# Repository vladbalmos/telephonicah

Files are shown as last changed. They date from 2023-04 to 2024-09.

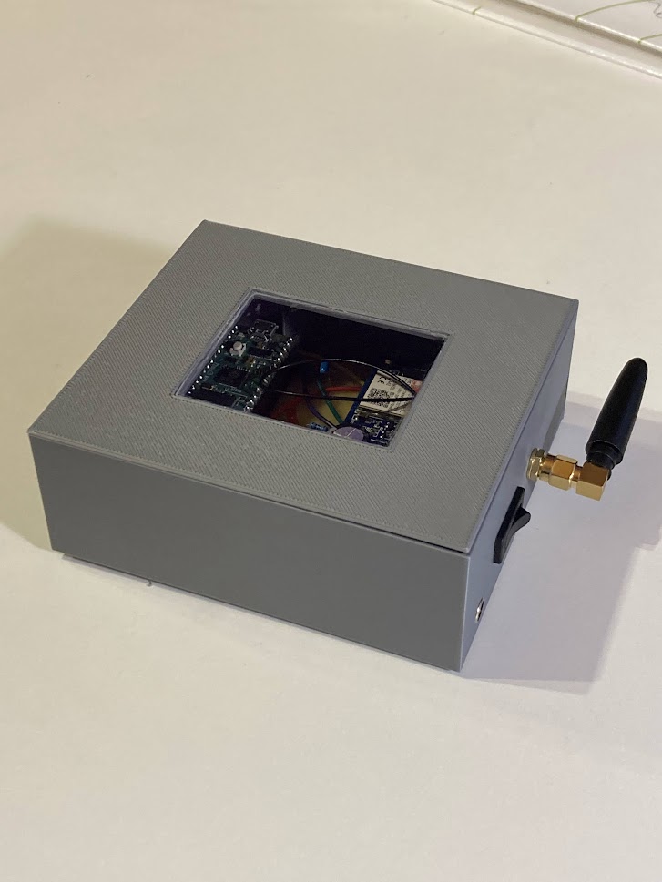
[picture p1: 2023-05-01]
hw/telephonicah.jpg

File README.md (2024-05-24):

# UPDATE
The original version of this project is on branch `original-call-proxy`. The `master` branch doesn't forward calls to a designated number, instead it activates an external connected remote control using the signal port (see the schematic in the `hw` folder for the signal port pinout).
# Telephonicah

This repo contains firmware and hardware related resources (schematic, pcb & enclosure 3d models) for a device used to proxy GSM calls to a designated number (ex: parking barrier gate).

Hardware requirements:

    * Raspberry Pi Pico W
    * SIM800 GSM Module
    * 5V@2.5A power supply
    * capacitors: 100nf, 4.7uf, 2200uf
    * resistors: 2x150ohm, 1Mohm
    * leds: red, green
    
The Pico controls the SIM800 module via UART.

Features:

    * SMS based commands:
        * get remaining credit
        * delete SIM stored SMSs
        * connect to wifi
        * query wifi status
    * Relay received SMS to designated owner number
    * Web UI
    
After the devices connects to WIFI it will bind the webserver to port 8080 and a SMS containing the server's ip address and port will be sent to the administrator's phone number

# System requirements
* micropython
* ampy (pip3 install adafruit-ampy)
* minicom (optional)

# Development

## Linux
Build micropython:

    cd [mycropython-dir]
    make -C mpy-cross

    cd [mycropython-dir]/ports/rp2
    make -j4 BOARD=PICO_W submodules
    make -j4 BOARD=PICO_W clean
    make -j4 BOARD=PICO_W
    
After building copy the micropython firmware to a pico

Init:
    ./setup.sh
    # edit src/phone_numbers.py and add phone numbers
    make build
    
Run:

    make run
    
Clean

    make clean
    
Build

    make build

## Windows
Build micropython https://github.com/micropython/micropython/tree/master/ports/windows

After building copy the micropython firmware to a pico

Edit `build.ps1` and change the $PORT variable to the correct serial port (ex: com1)
Init:

    .\setup.ps1
    # edit src/phone_numbers.py and add phone numbers
    .\build.ps1 -Command build
    
Run:

    .\build.ps1 -Command run

Clean:

    .\build.ps1 -Command clean
    
Build:

    .\build.ps1 -Command build

List files on pico:

    .\build.ps1 -Command list
    
Copy file from pico:

    .\build.ps1 -Command get -Argument [filename]
    
Copy file to pico:

    .\build.ps1 -Command send -Argument [filename]

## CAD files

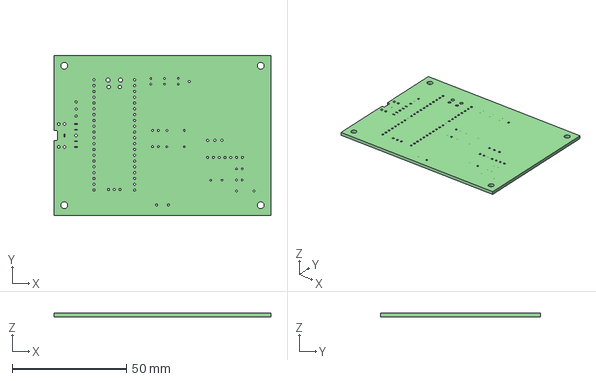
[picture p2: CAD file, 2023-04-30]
hw/board/telephonica/telephonica.step
95.0 x 70.0 x 1.60 mm

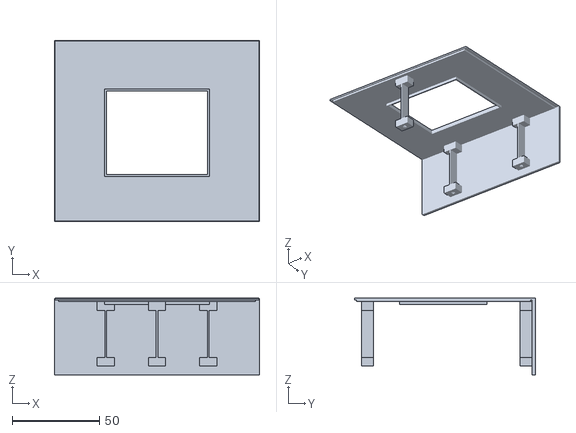
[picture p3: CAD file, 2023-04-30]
hw/case/body-Part_Lid.stl
117.5 x 104.0 x 44.0

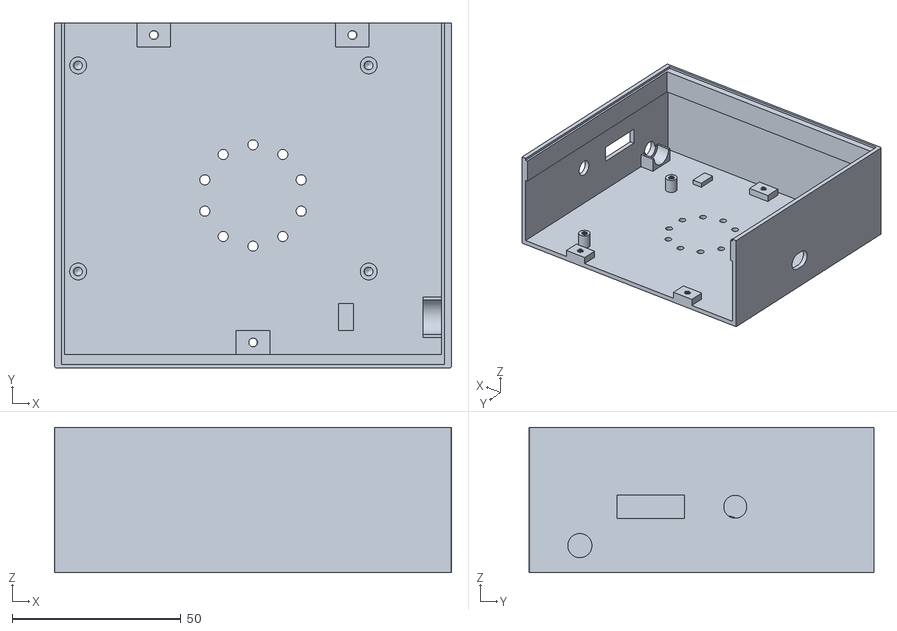
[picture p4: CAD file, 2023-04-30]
hw/case/body-Part_Body.stl
117.5 x 102.0 x 43.0

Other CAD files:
hw/case/pcb.stl

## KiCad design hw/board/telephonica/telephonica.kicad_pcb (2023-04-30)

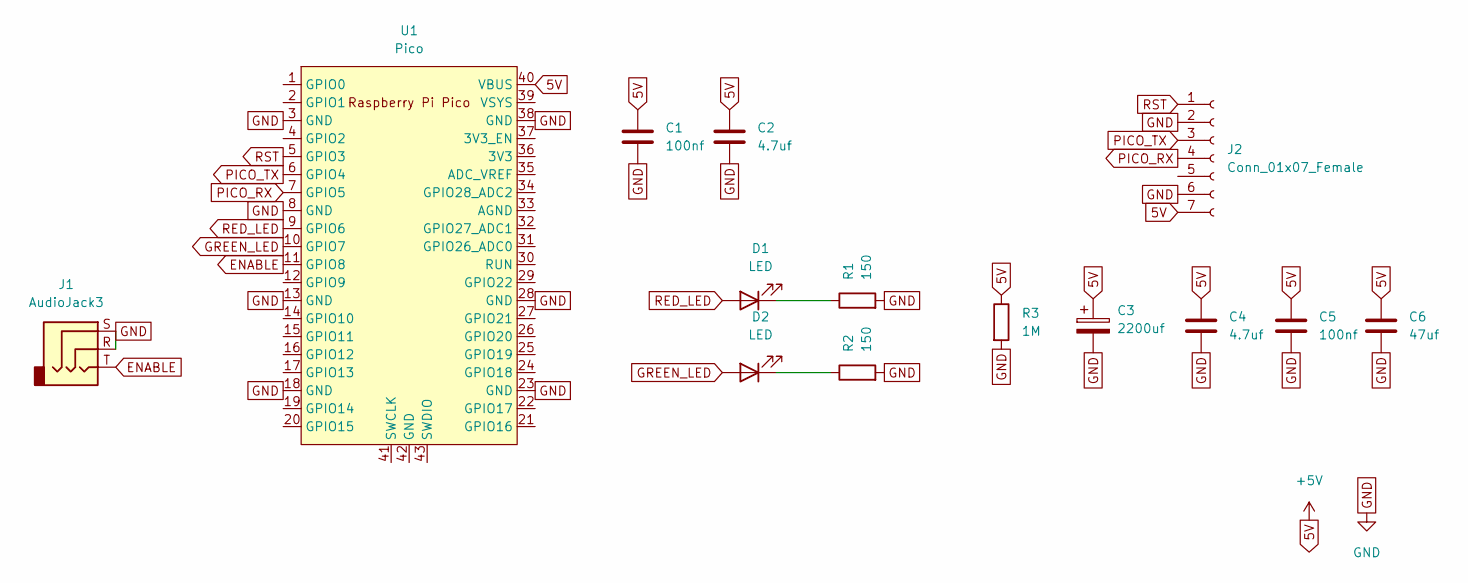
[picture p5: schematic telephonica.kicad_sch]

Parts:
C1, C5: 100nf; C_Disc_D3.8mm_W2.6mm_P2.50mm
C2, C4: 4.7uf; C_Disc_D3.8mm_W2.6mm_P2.50mm
C3: 2200uf; C_Radial_D12.5mm_H20.0mm_P5.00mm
C6: 47uf; C_Disc_D3.8mm_W2.6mm_P2.50mm
D1, D2: LED; LED_D5.0mm
J1: AudioJack3; Jack_3.5mm_CUI_SJ1-3525N_Horizontal
J2: Conn_01x07_Female; PinHeader_1x07_P2.54mm_Vertical
R1, R2: 150; R_Axial_DIN0207_L6.3mm_D2.5mm_P7.62mm_Horizontal
R3: 1M; R_Axial_DIN0207_L6.3mm_D2.5mm_P7.62mm_Horizontal
U1: Pico; RPi_Pico_SMD_TH

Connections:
5V: C1.1, C2.1, C3.1, C4.1, C5.1, C6.1, J2.7, R3.1, U1.40 (VBUS)
ENABLE: J1.T, U1.11 (GPIO8)
GND: C1.2, C2.2, C3.2, C4.2, C5.2, C6.2, J1.R, J1.S, J2.2, J2.6, R1.2, R2.2, R3.2, U1.3 (GND), U1.8 (GND), U1.13 (GND), U1.18 (GND), U1.23 (GND), U1.28 (GND), U1.38 (GND)
GREEN_LED: D2.2 (A), U1.10 (GPIO7)
unnamed: D1.1 (K), R1.1
unnamed: D2.1 (K), R2.1
PICO_RX: J2.4, U1.7 (GPIO5)
PICO_TX: J2.3, U1.6 (GPIO4)
RED_LED: D1.2 (A), U1.9 (GPIO6)
RST: J2.1, U1.5 (GPIO3)

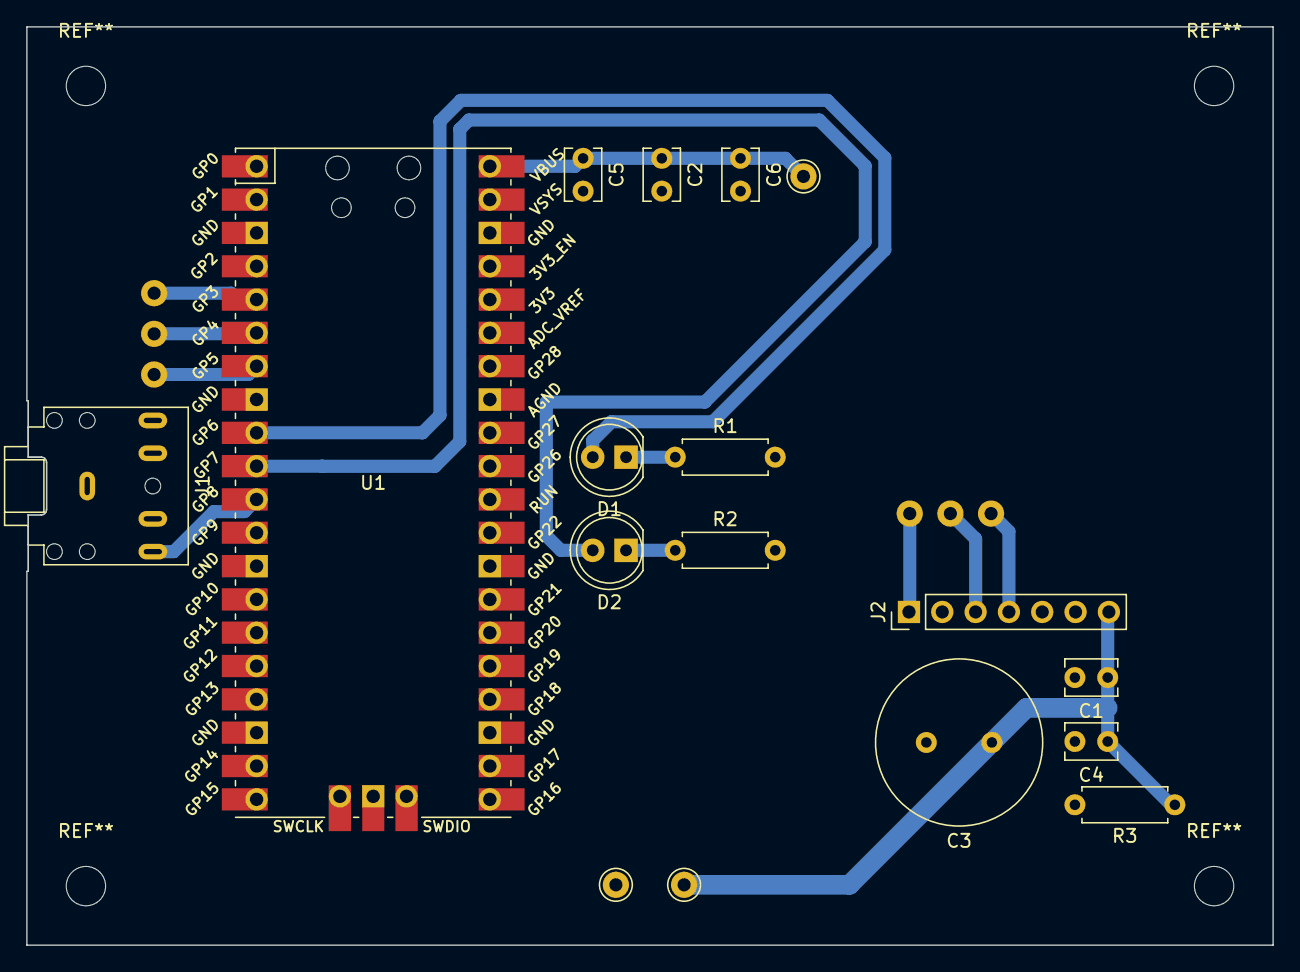
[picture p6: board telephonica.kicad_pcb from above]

Board: 2 copper layers, 95.0 x 70.0 mm, 14 parts (0 on the bottom side), 10 nets.

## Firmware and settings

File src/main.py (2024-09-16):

import machine
import uasyncio as asyncio
import json
import time
import sim800l
import os
import uart
from dynamic_queue import Queue
import phone_numbers
import led_notif
import webserver

SLEEP_MS = 50

RST_PIN = 3
TX_PIN = 4
RX_PIN = 5
RED_LED_PIN = 6
GREEN_LED_PIN = 7
ENABLE_PIN = 8

watchdog = machine.WDT(timeout=8000)
watchdog.feed()
wifi_status_sms_sent = False
last_reset = None
sim_reset_counts = 0

reset_pin = machine.Pin(RST_PIN, machine.Pin.OUT)
reset_pin.high()

enable_pin = machine.Pin(ENABLE_PIN, machine.Pin.OUT)
enable_pin.low()

state = {
    'gate_number': phone_numbers.GATE_NUMBER,
    'owner_number': phone_numbers.OWNER_NUMBER,
    'ep_toggle_duration': 500,
    'allowed_callers': phone_numbers.ALLOWED_CALLERS.copy(),
    'ssid': None,
    'ssid_password': None
}

available_commands = [
    'get:credit',
    'delete:sms',
    'clear:state',
    'wifi:status',
    'wifi:connect\nssid\npassword'
]

async def sleep(ms = SLEEP_MS):
    return await asyncio.sleep_ms(ms)

async def toggle_enable_pin(duration = 500):
    print('Toggling ENABLE PIN for', duration, 'ms')
    enable_pin.high()
    await sleep(duration)
    enable_pin.low()

async def main():
    global state
    global wifi_status_sms_sent
    
    led = machine.Pin('LED', machine.Pin.OUT)
    red_led = machine.Pin(RED_LED_PIN, machine.Pin.OUT)
    green_led = machine.Pin(GREEN_LED_PIN, machine.Pin.OUT)
    
    led_notif.initialize(red_led, green_led)

    device_queue = Queue(24)
    debug_queue = Queue(24)
    command_queue = Queue(8)

    uart_config = {
        'tx': machine.Pin(TX_PIN, machine.Pin.OUT),
        'rx': machine.Pin(RX_PIN, machine.Pin.IN),
        'timeout': 250
    }

    reader, writer = await uart.initialize(uart_config)
    asyncio.create_task(sim800l.initialize(device_queue, debug_queue, reader, writer, watchdog))
    
    watchdog.feed()
    try:
        with open('state.json', 'r') as state_file:
            contents = state_file.read()
            state = json.loads(contents)
    except Exception as e:
        print('No last state found')

    if state['ssid'] and state['ssid_password']:
        asyncio.create_task(webserver.initialize(command_queue, state, state['ssid'], state['ssid_password']))
        
    credit_info = ''
    last_credit_info_msg = None
    last_event = 0
    failed_wifi_connects = 0
    wifi_connected = False
    first_time_initialized = False
    loop_start = time.ticks_ms()
        
    watchdog.feed()

    while True:
        led.toggle()
        now = time.ticks_ms()
        
        if not first_time_initialized:
            elapsed_initalization = time.ticks_diff(now, loop_start)
            
            if elapsed_initalization < (60 * 1000):
                print("Feeding watch dog while initializing")
                watchdog.feed()

        if last_credit_info_msg:
            last_event = now
            diff = time.ticks_diff(now, last_credit_info_msg)
            if diff > 10 * 1000:
                asyncio.create_task(sim800l.send_sms_with_lock(state['owner_number'], credit_info))
                credit_info = ''
                last_credit_info_msg = None
            
        while not device_queue.empty():
            last_event = now
            event = device_queue.get_nowait()
            log_event = True

            if event['event'] == 'incoming-event':
                log_event = False
                led_notif.start_blink_green(1000)
                print('device', event)
            elif event['event'] == 'outgoing-event':
                log_event = False
                led_notif.start_blink_green(3000)
                print('device', event)
            elif event['event'] == 'initializing':
                log_event = False
                led_notif.start_blink_red()
                print('device', event)
            elif event['event'] == 'initialized':
                first_time_initialized = True
                print("Feeding watch dog")
                watchdog.feed()
                log_event = False
                await led_notif.stop_blink_red()
            else:
                print('device', event)

            if log_event:
                webserver.logs_queue.put_nowait(event)
                
            if event['event'] == 'incoming-call':
                caller = event['caller']
                if caller in state['allowed_callers']:
                    asyncio.create_task(toggle_enable_pin(int(state['ep_toggle_duration'])))
                    asyncio.create_task(sim800l.open_gate(state['gate_number'], caller))
                else:
                    await sim800l.decline_call()
            
            if event['event'] == 'incoming-sms':
                if type(event['data']) is tuple and len(event['data']) == 3:
                    msg_details = event['data'][2] or []
                    msg_from_owner = False
                    msg_from_credit_info = False
                    await sim800l.delete_sms(event['index'])
                    for d in msg_details:
                        if state['owner_number'] in d:
                            msg_from_owner = True
                            break
                        if "Credit Info" in d:
                            msg_from_credit_info = True
                            break
                        
                    if msg_from_owner:
                        msg = event['data'][2]
                        msg = '\n'.join(msg[1:])
                        original_msg = msg
                        if msg:
                            msg = msg.lower().strip()
                        if msg == 'help:':
                            msg = '\n'.join(available_commands)
                            asyncio.create_task(sim800l.send_sms_with_lock(state['owner_number'], msg))
                        if msg == 'get:credit':
                            asyncio.create_task(sim800l.check_credit())
                        elif msg == 'delete:sms':
                            await sim800l.delete_sms(aquire_lock=True, delete_all=True)
                        elif msg == 'clear:state':
                            print('Clearing state and rebooting')
                            try:
                                os.remove('state.json')
                                print('State removed. Rebooting')
                                return machine.reset()
                            except:
                                print('No state to clear')
                        elif msg == 'wifi:status':
                            wifi_status, details = webserver.status()
                            msg = f'Status: {wifi_status}\n Details: {json.dumps(details)}'
                            asyncio.create_task(sim800l.send_sms_with_lock(state['owner_number'], msg))
                        elif 'wifi:connect' in msg:
                            segments = original_msg.strip().split('\n')
                            if len(segments) != 3:
                                continue
                            
                            ssid = segments[1]
                            password = segments[2]
                            asyncio.create_task(webserver.initialize(command_queue, state, ssid, password))
                            print(f'Will connect to {ssid}/{password}')
                    elif msg_from_credit_info:
                        msg = event['data'][2]
                        msg = '\n'.join(msg[1:])
                        credit_info = f'{credit_info}{msg}'
                        last_credit_info_msg = time.ticks_ms()
                
        while not debug_queue.empty():
            last_event = now
            info = debug_queue.get_nowait()
            webserver.logs_queue.put_nowait(info)
            print('debug', info)
            
        state_modified = False
        while not command_queue.empty():
            last_event = now
            cmd = command_queue.get_nowait()
            print('command', cmd)
            webserver.logs_queue.put_nowait(cmd)
            if cmd['do'] == 'notif-wifi-connecting':
                led_notif.start_blink_red()
            
            if cmd['do'] == 'reset':
                print('Reseting...')
                machine.reset()
            if cmd['do'] == 'enter-debug':
                sim800l.toggle_debug_mode(True)
            if cmd['do'] == 'delete-all-sms':
                print('Deleting all sms')
                await sim800l.delete_sms(aquire_lock=True, delete_all=True)
            if cmd['do'] == 'send-at-command':
                await sim800l.send_at_command(cmd['payload']);
            if cmd['do'] == 'update-allowed-callers':
                new_dict = {}
                for name, number in cmd['payload']:
                    new_dict[number] = name
                state['allowed_callers'] = new_dict
                state_modified = True
            elif cmd['do'] == 'update-gate-number':
                state['gate_number'] = cmd['payload']
                state_modified = True
            elif cmd['do'] == 'update-ep-toggle-duration':
                try:
                    state['ep_toggle_duration'] = int(cmd['payload'])
                    state_modified = True
                except:
                    pass
            elif cmd['do'] == 'update-owner-number':
                state['owner_number'] = cmd['payload']
                state_modified = True
            elif cmd['do'] == 'check-credit':
                asyncio.create_task(sim800l.check_credit())
            elif cmd['do'] == 'handle-wifi-status':
                await led_notif.stop_blink_red()
                result = cmd['payload']
                if result['status']:
                    state['ssid'] = result['ssid']
                    state['ssid_password'] = result['password']
                    state['ip'] = result['ip']
                    state['port'] = result['port']
                    state_modified = True
                    
                    ip = state['ip']
                    port = state['port']
                    msg = f'Connected: {ip}:{port}'
                    wifi_connected = True
                else:
                    failed_wifi_connects += 1
                    try:
                        error_code = webserver.wifi_status_codes[result['code']]
                    except KeyError:
                        error_code = 'unknown-status'
                    msg = f'Unable to connect to wifi: {error_code}'
                    
                if not wifi_status_sms_sent:
                    if wifi_connected or failed_wifi_connects >= 5:
                        asyncio.create_task(sim800l.send_sms_with_lock(state['owner_number'], msg))
                        wifi_status_sms_sent = True
            else:
                continue
                
        if state_modified:
            try:
                with open('state.json', 'w') as state_file:
                    state_file.write(json.dumps(state))
            except Exception as e:
                print('Caught exception while writing state', e)
                webserver.logs_queue.put_nowait({'event': 'error', 'msg': f'Exception while writing state failed {e.args[0]}'})
                
        elapsed_since_last_event = now - last_event
        if elapsed_since_last_event > (120 * 1000) and not sim800l.debug_mode:
            print("Resetting due to inactivity. This shouldn't happen\n")
            machine.reset()
        
        await sleep()
    
asyncio.run(main())
asyncio.new_event_loop()

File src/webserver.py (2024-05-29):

import time
import json
import uasyncio as asyncio
import network
import os
    
server_initialized = False
command_queue = None
debug_mode = False
state = None
start_ticks = time.ticks_ms()

wlan = None
ssid = None
ip = None
port = None
wifi_connected_msg_logged = False

wifi_status_codes = {
    network.STAT_IDLE: 'idle',
    network.STAT_CONNECTING: 'connecting',
    network.STAT_WRONG_PASSWORD: 'wrong-password',
    network.STAT_NO_AP_FOUND: 'no-access-point',
    network.STAT_CONNECT_FAIL: 'unknown-error',
    network.STAT_GOT_IP: 'connected'
}

def tstamp():
    now = time.ticks_ms()
    return time.ticks_diff(now, start_ticks) / 1000

class LogsQueue():

    def __init__(self, size=16):
        self.logs = []
        self._max_size = size
        
    def put_nowait(self, item):
        if not server_initialized:
            return

        if len(self.logs) == self._max_size:
            self.logs.pop(0)
            
        self.logs.append((tstamp(), item))
        
logs_queue = LogsQueue()

def url_decode(encoded_str):
    decoded_str = ''
    i = 0
    while i < len(encoded_str):
        if encoded_str[i] == '%' and i + 2 < len(encoded_str):
            hex_value = encoded_str[i + 1:i + 3]
            decoded_char = chr(int(hex_value, 16))
            decoded_str += decoded_char
            i += 3
        elif encoded_str[i] == '+':
            decoded_str += ' '
            i += 1
        else:
            decoded_str += encoded_str[i]
            i += 1
    return decoded_str

async def sleep(ms = 1000):
    return await asyncio.sleep_ms(ms)

async def wifi_connect(_ssid, ssid_password):
    global ssid
    global ip
    global wlan
    global wifi_connected_msg_logged
    
    ssid = _ssid
    
    if not wlan:
        command_queue.put_nowait({'do': 'notif-wifi-connecting'})
        wlan = network.WLAN(network.STA_IF)
        print('Creating WLAN')

    if not wlan.active():
        print('Setting WLAN active')
        wlan.active(True)
        
    if wlan.isconnected():
        if wifi_connected_msg_logged is False:
            config = wlan.ifconfig()
            ip = config[0]
            command_queue.put_nowait({'do': 'handle-wifi-status', 'payload': {'status': True, 'ip': ip, 'port': port, 'ssid': ssid, 'password': ssid_password}})
            print("WIFI connected")
            wifi_connected_msg_logged = True
        return
    
    print(f'Connecting to WIFI {ssid} using {ssid_password}')
    wlan.connect(ssid, ssid_password)
    
    max_wait = 10
    
    while max_wait > 0:
        status = wlan.status()
        print(f"Wifi status is: {status}")
        if status >= 3:
            break
        max_wait -= 1
        print('Waiting for connection')
        await sleep(1000)
        

    status = wlan.status()
    try :
        str_status = wifi_status_codes[status]
    except KeyError:
        str_status = 'unknown-status'
        
    if status != network.STAT_GOT_IP:
        print(f'WIFI Status is {status}/{str_status}')
        command_queue.put_nowait({'do': 'handle-wifi-status', 'payload': {'status': False, 'code': status}})
        return
    
    config = wlan.ifconfig()
    ip = config[0]
    command_queue.put_nowait({'do': 'handle-wifi-status', 'payload': {'status': True, 'ip': ip, 'port': port, 'ssid': ssid, 'password': ssid_password}})
    print("WIFI connected")

def parse_params(str_params):
    params = str_params.split('&')
    
    query_params = []

    for p in params:
        if not len(p):
            continue

        p_segments = p.split('=')
        name = p_segments.pop(0)
        if not name:
            continue
        
        value = '='.join(p_segments)
        if name != 'atcommand':
            query_params.append((name, url_decode(value)))
        else:
            query_params.append((name, value))
        
    return query_params

def parse_uri(uri):
    if '?' not in uri:
        return uri, []
    
    segments = uri.split('?')
    
    uri = segments.pop(0)
    params = '?'.join(segments)
    query_params = parse_params(params)
        
    return uri, query_params

def parse_form_data(str_form):
    url_decoded_form = url_decode(str_form)
    decoded_form_data = parse_params(url_decoded_form)
    
    data = {}
    for item in decoded_form_data:
        key, value = item
        if key != 'atcommand':
            value = url_decode(value.strip())
        if '[]' in key:
            key = key[0:-2]
            
            if key not in data:
                data[key] = []
        
            data[key].append(value)
        else:
            data[key] = value
            
    return data
                
    

async def serve_index(method, _headers, _query, _body):
    if method == 'post':
        return '404', 'Not found', [], ''
    
    def stream_response(writer):
        with open('index.html', 'r') as file:
            allowed_callers = []
            for phone, name in state['allowed_callers'].items():
                item = f'<li id="{phone}">{phone} - {name} <input type="hidden" name="name[]" value="{name}"><input type="hidden" name="phone[]" value="{phone}"> <a href="#" rel="{phone}" class="delete-icon" title="Șterge"></a></li>\n'
                allowed_callers.append(item)

            while True:
                line = file.readline()
                if not line:
                    break
                
                if '{debug_mode}' in line:
                    value = '0'
                    if debug_mode:
                        value = '1'
                    line = line.replace('{debug_mode}', value)
                
                if line.strip() == '{allowed_callers}':
                    for caller in allowed_callers:
                        writer.write(caller)
                    continue
                        
                if line.strip() == '{logs}':
                    for (tstamp, item) in logs_queue.logs:
                        writer.write(f'{tstamp} - {item}\n')
                    continue
                
                if '{current_owner}' in line:
                    line = line.replace('{current_owner}', state['owner_number'])

                if '{gate}' in line:
                    line = line.replace('{gate}', state['gate_number'])
                    
                if '{ep-toggle-duration}' in line:
                    line = line.replace('{ep-toggle-duration}', str(state['ep_toggle_duration']))
                    
                writer.write(line.encode('utf8'))
            
    return '200', 'OK', [], stream_response
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

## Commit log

2023-04-27 Add case 3d model
2023-04-30 Add hardware resources
    [body-Part_Body.stl, body-Part_Lid.stl, pcb.stl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]
2023-07-22 Reliability improvements
    * add watchdog to reset device in case of failure
    * increase waiting timeout when calling gate & retry in case of failure
    * store fail logs during call gate procedure
    * retrieve fail logs using webserver
    [main.py, sim800l.py, webserver.py]
2024-05-24 Make the duration for setting the enable pin high user configurable
2024-05-29 Bug fixes and improvements
    [main.py, sim800l.py, webserver.py]
2024-09-16 Remove reset sim functionality
    [main.py]
